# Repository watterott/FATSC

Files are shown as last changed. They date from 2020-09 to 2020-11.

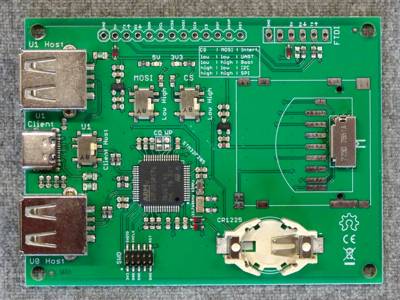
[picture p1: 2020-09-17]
hardware/FATSC-DevKit_v10.jpg

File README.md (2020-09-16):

# FATSC
FATSC (FAT Storage Controller) is a SD/USB coprocessor to connect USB memory sticks or SD cards to a microcontroller.

* USB-Host MSD/MSC port
* SD-Card interface
* Real-Time-Clock (RTC)
* FAT/FAT32 file system
* Based on a ST STM32F205 ARM microcontroller
* ALFAT compatible pinout and commands
* **[Documentation on learn.watterott.com](https://learn.watterott.com)**

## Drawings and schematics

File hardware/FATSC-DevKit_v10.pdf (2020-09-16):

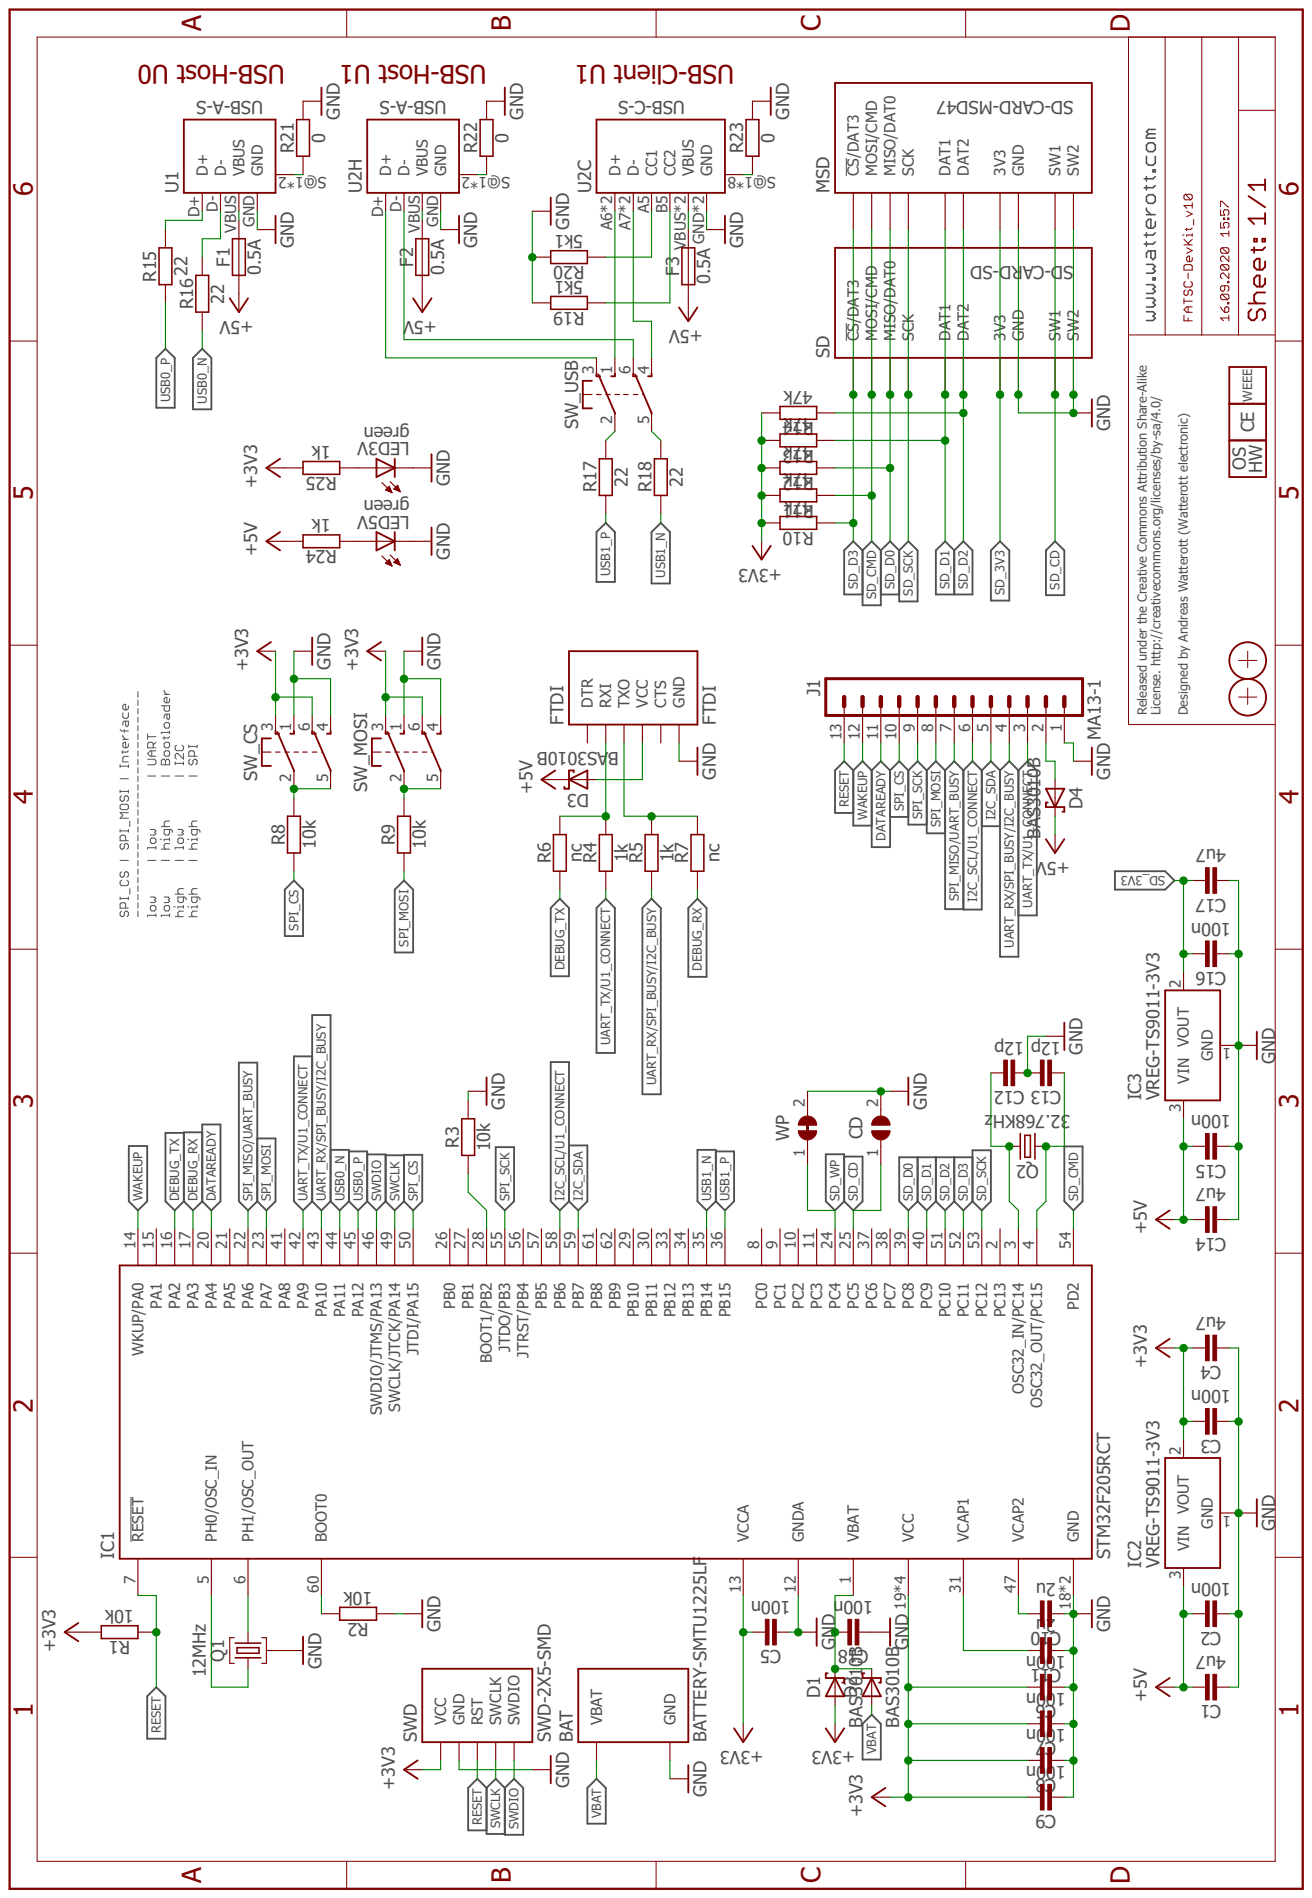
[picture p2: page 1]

Released under the Creative Commons Attribution Share-Alike

2 OS HW CE WEEE

License. http://creativecommons.org/licenses/by-sa/4.0/ Designed by Andreas Watterott (Watterott electronic)

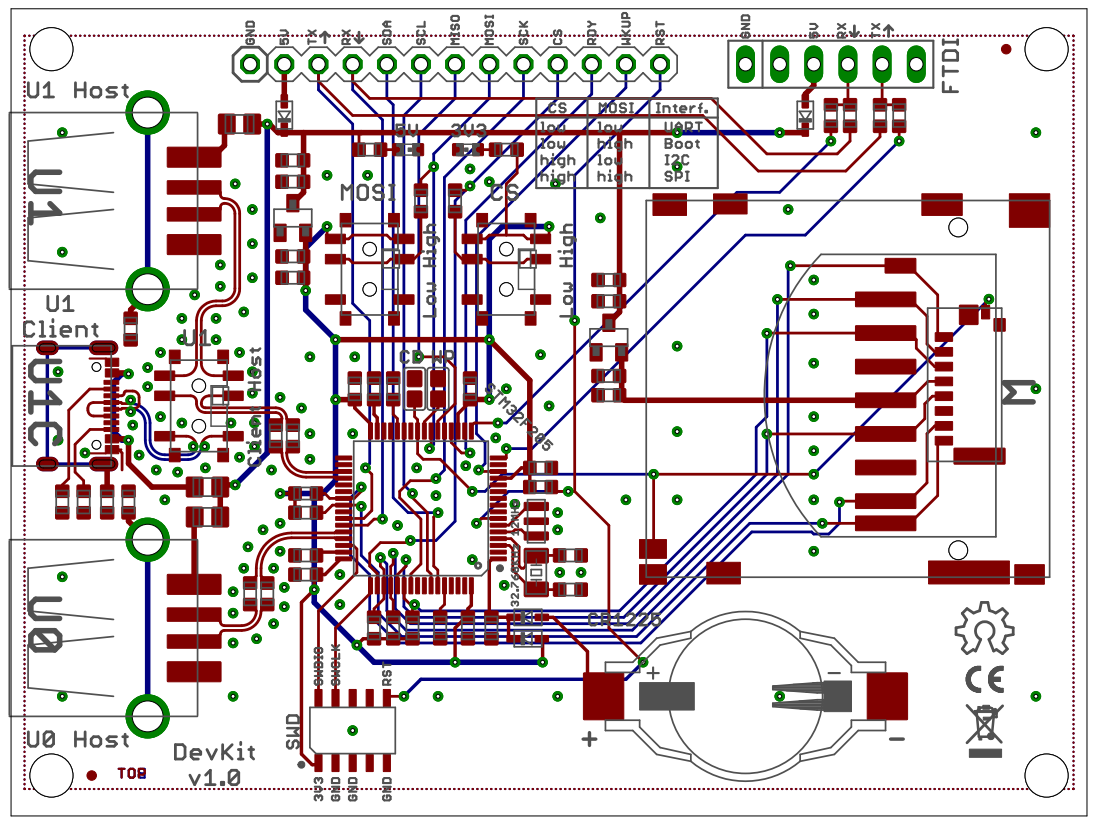
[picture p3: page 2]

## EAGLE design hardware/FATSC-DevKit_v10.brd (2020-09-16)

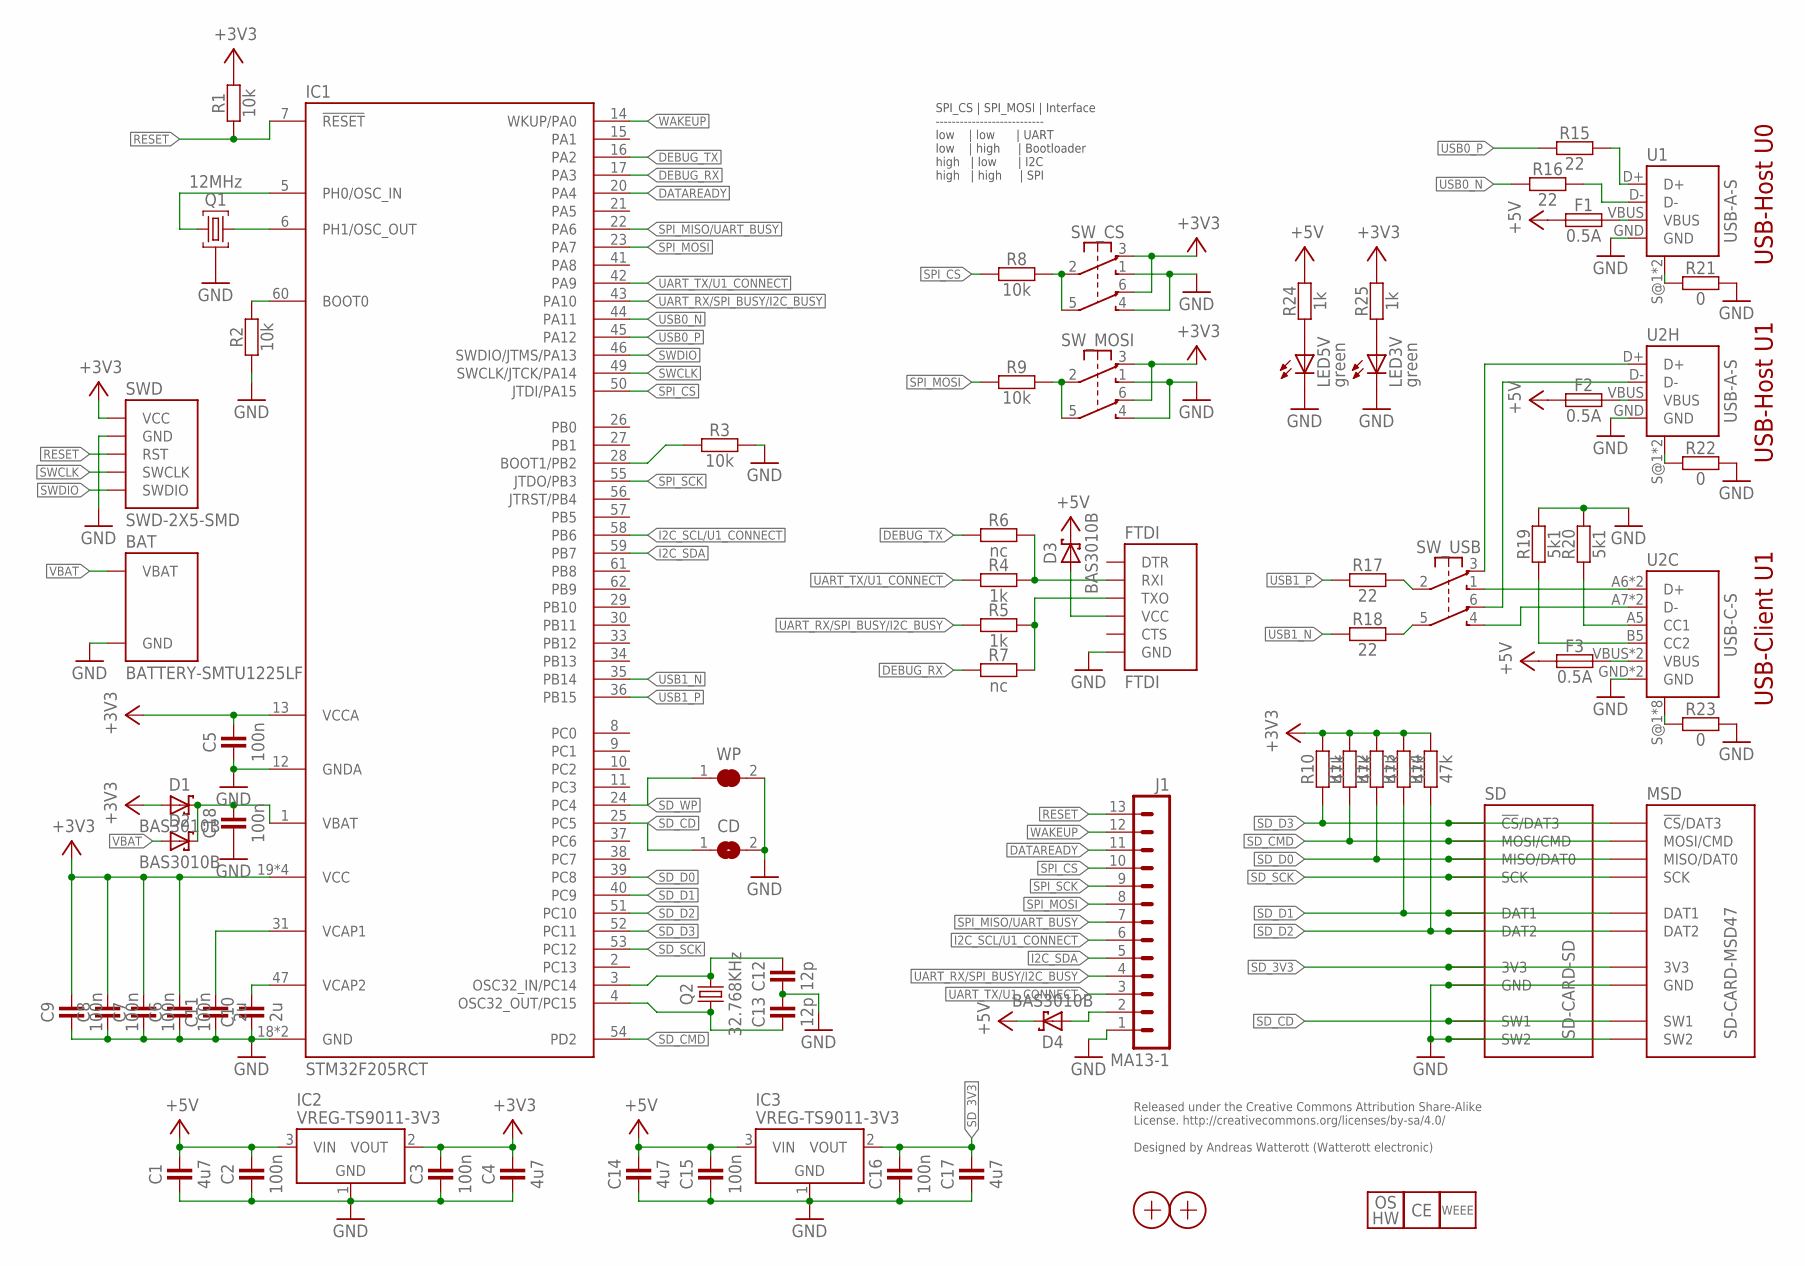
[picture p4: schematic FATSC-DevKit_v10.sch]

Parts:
BAT: BATTERY-SMTU1225LF; BAT-SMTU1225LF
C1, C4, C14, C17: 4u7; C0603
C2, C3, C5, C6, C7, C8, C9, C15, C16, C18: 100n; C0603
C10, C11: 2u; C0603
C12, C13: 12p; C0603
CD: JUMPER2-0603-NC; JUMPER2-0603_NC
D1, D2, D3, D4: BAS3010B; SOD323
F1, F2, F3: 0.5A; C0805
FTDI: FTDI
IC1: STM32F205RCT; LQFP64
IC2, IC3: VREG-TS9011-3V3; SOT23
J1: MA13-1
LED3V, LED5V: green; C0603
LOGO7: LOGO_OSHW-4; OSHW_4MM
LOGO8: LOGO_CE-2; CE_2MM
LOGO9: LOGO_WEEE-4; WEEE_4MM
MSD: SD-CARD-MSD47; SD_47309XXXX
Q1: 12MHz; CRYSTAL_32X13
Q2: 32.768KHz; CRYSTAL_ZM315
R1, R2, R3, R8, R9: 10k; C0603
R4, R5, R24, R25: 1k; C0603
R6, R7: nc; C0603
R10, R11, R12, R13, R14: 47k; C0603
R15, R16, R17, R18: 22; C0603
R19, R20: 5k1; C0603
R21, R22, R23: 0; C0603
SD: SD-CARD-SD; SD_SDBMF00915B0T2
SWD: SWD-2X5-SMD; SWD-2X5_SMD
SW_CS: SW-2UM-CUS22B; CUS22B
SW_MOSI: SW-2UM-CUS22B; CUS22B
SW_USB: SW-2UM-CUS22B; CUS22B
U1, U2H: USB-A-S
U2C: USB-C-S
WP: JUMPER2-0603
X1, X2: PASSER-07; PASSER_07MM

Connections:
5VIN: D4.A, J1.2
+3V3: C3.2, C4.2, C5.2, C6.2, C7.2, C8.2, C9.2, D1.A, IC1.13 (VCCA), IC1.19 (VCC), IC1.32 (VCC), IC1.48 (VCC), IC1.64 (VCC), IC2.2 (VOUT), R1.2, R10.2, R11.2, R12.2, R13.2, R14.2, R25.2, SWD.VCC, SW_CS.3 (NC1), SW_CS.6 (NC2), SW_MOSI.3 (NC1), SW_MOSI.6 (NC2)
+5V: C1.2, C2.2, C14.2, C15.2, D3.C, D4.C, F1.1, F2.1, F3.1, IC2.3 (VIN), IC3.3 (VIN), R24.2
BOOT0: IC1.60 (BOOT0), R2.2
BOOT1: IC1.28 (BOOT1/PB2), R3.1
CC1: R20.1, U2C.A5 (CC1)
CC2: R19.1, U2C.B5 (CC2)
CS: R8.2, SW_CS.2 (C1), SW_CS.5 (C2)
D0_N: R16.2, U1.D-
D0_P: R15.2, U1.D+
D1C_N: SW_USB.4 (NO2), U2C.A7 (D-), U2C.B7 (D-)
D1C_P: SW_USB.1 (NO1), U2C.A6 (D+), U2C.B6 (D+)
D1H_N: SW_USB.6 (NC2), U2H.D-
D1H_P: SW_USB.3 (NC1), U2H.D+
D1_N: R18.2, SW_USB.5 (C2)
D1_P: R17.2, SW_USB.2 (C1)
DATAREADY: IC1.20 (PA4), J1.11
DEBUG_RX: IC1.17 (PA3), R7.1
DEBUG_TX: IC1.16 (PA2), R6.1
FTDI_VCC: D3.A, FTDI.3-VCC (VCC)
GND: BAT.- (GND), C1.1, C2.1, C3.1, C4.1, C5.1, C6.1, C7.1, C8.1, C9.1, C10.1, C11.1, C12.1, C13.2, C14.1, C15.1, C16.1, C17.1, C18.1, CD.2, FTDI.1-GND (GND), IC1.12 (GNDA), IC1.18 (GND), IC1.63 (GND), IC2.1 (GND), IC3.1 (GND), J1.1, LED3V.C, LED5V.C, MSD.GND, MSD.GND@1 (GND), MSD.GND@2 (GND), MSD.SW2, Q1.GND, R2.1, R3.2, R19.2, R20.2, R21.2, R22.2, R23.2, SD.GND@1 (GND), SD.GND@2 (GND), SD.GND@3 (GND), SD.SW2, SWD.GND@1 (GND), SWD.GND@2 (GND), SWD.GND@3 (GND), SW_CS.1 (NO1), SW_CS.4 (NO2), SW_MOSI.1 (NO1), SW_MOSI.4 (NO2), U1.GND, U2C.GND, U2C.GND2 (GND), U2H.GND, WP.2
I2C_SCL/U1_CONNECT: IC1.58 (PB6), J1.6
I2C_SDA: IC1.59 (PB7), J1.5
MOSI: R9.2, SW_MOSI.2 (C1), SW_MOSI.5 (C2)
unnamed: LED5V.A, R24.1
unnamed: LED3V.A, R25.1
OSC32I: C12.2, IC1.3 (OSC32_IN/PC14), Q2.2
OSC32O: C13.1, IC1.4 (OSC32_OUT/PC15), Q2.1
OSCI: IC1.5 (PH0/OSC_IN), Q1.2
OSCO: IC1.6 (PH1/OSC_OUT), Q1.1
RESET: IC1.7 (!RESET), J1.13, R1.1, SWD.RST
RXI: FTDI.5-RXI (RXI), R4.2, R6.2
SD_3V3: C16.2, C17.2, IC3.2 (VOUT), MSD.VCC (3V3), SD.VCC (3V3)
SD_CD: CD.1, IC1.25 (PC5), MSD.SW1, SD.SW1
SD_CMD: IC1.54 (PD2), MSD.MOSI (MOSI/CMD), R11.1, SD.MOSI (MOSI/CMD)
SD_D0: IC1.39 (PC8), MSD.MISO (MISO/DAT0), R12.1, SD.MISO (MISO/DAT0)
SD_D1: IC1.40 (PC9), MSD.DAT1, R13.1, SD.DAT1
SD_D2: IC1.51 (PC10), MSD.DAT2, R14.1, SD.DAT2
SD_D3: IC1.52 (PC11), MSD.CS (!CS!/DAT3), R10.1, SD.CS (!CS!/DAT3)
SD_SCK: IC1.53 (PC12), MSD.SCK, SD.SCK
SD_WP: IC1.24 (PC4), WP.1
SPI_CS: IC1.50 (JTDI/PA15), J1.10, R8.1
SPI_MISO/UART_BUSY: IC1.22 (PA6), J1.7
SPI_MOSI: IC1.23 (PA7), J1.8, R9.1
SPI_SCK: IC1.55 (JTDO/PB3), J1.9
SU0: R21.1, U1.S@1 (SHIELD), U1.S@2 (SHIELD)
SU1C: R23.1, U2C.S@1 (SHIELD), U2C.S@2 (SHIELD), U2C.S@3 (SHIELD), U2C.S@4 (SHIELD), U2C.S@5 (SHIELD), U2C.S@6 (SHIELD), U2C.S@7 (SHIELD), U2C.S@8 (SHIELD)
SU1H: R22.1, U2H.S@1 (SHIELD), U2H.S@2 (SHIELD)
SWCLK: IC1.49 (SWCLK/JTCK/PA14), SWD.SWCLK
SWDIO: IC1.46 (SWDIO/JTMS/PA13), SWD.SWDIO
TXO: FTDI.4-TXO (TXO), R5.2, R7.2
UART_RX/SPI_BUSY/I2C_BUSY: IC1.43 (PA10), J1.4, R5.1
UART_TX/U1_CONNECT: IC1.42 (PA9), J1.3, R4.1
USB0_N: IC1.44 (PA11), R16.1
USB0_P: IC1.45 (PA12), R15.1
USB1_N: IC1.35 (PB14), R18.1
USB1_P: IC1.36 (PB15), R17.1
VB: C18.2, D1.C, D2.C, IC1.1 (VBAT)
VBAT: BAT.+ (VBAT), D2.A
VBUS_U0: F1.2, U1.VBUS
VBUS_U1C: F3.2, U2C.VBUS, U2C.VBUS2 (VBUS)
VBUS_U1H: F2.2, U2H.VBUS
VCAP1: C11.2, IC1.31 (VCAP1)
VCAP2: C10.2, IC1.47 (VCAP2)
WAKEUP: IC1.14 (WKUP/PA0), J1.12

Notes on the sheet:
Released under the Creative Commons Attribution Share-Alike License. http://creativecommons.org/licenses/by-sa/4.0/ Designed by Andreas Watterott (Watterott electronic)
USB-Host U0
USB-Host U1
USB-Client U1
SPI_CS | SPI_MOSI | Interface --------------------------- low | low | UART low | high | Bootloader high | low | I2C high | high | SPI

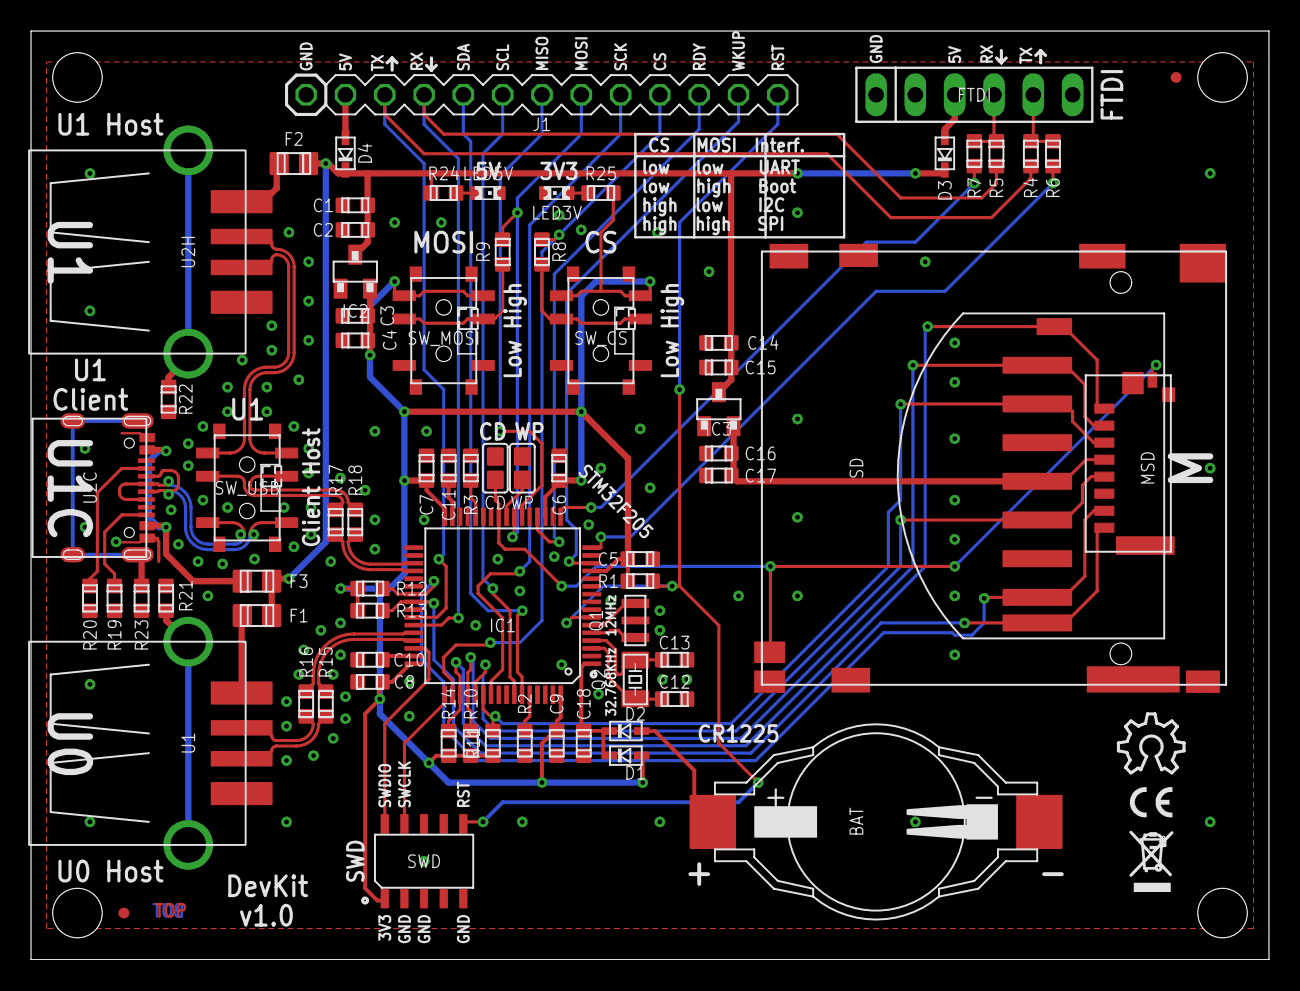
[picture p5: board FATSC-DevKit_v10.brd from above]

Board: 2 copper layers, 80.0 x 60.0 mm, 76 parts (0 on the bottom side), 65 nets.

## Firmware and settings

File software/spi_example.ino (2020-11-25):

/*
  FATSC SPI Demo
 */

#include <SPI.h>


#define RST_PIN    9 //Reset (FATSC reset input pin not 5V tolerant)
#define CS_PIN    10 //CS/SS chip select
#define MOSI_PIN  11 //SDI/MOSI (ICSP: 4, Uno: 11, Mega: 51)
#define MISO_PIN  12 //SDO/MISO (ICSP: 1, Uno: 12, Mega: 50)
#define SCK_PIN   13 //CLK/SCK  (ICSP: 3, Uno: 13, Mega: 52)
#define READY_PIN  8 //Data ready
#define BUSY_PIN   7 //Busy

#define BYTE_PAUSE 5 //us pause between SPI data bytes

#define CR    0x0D
#define LF    0x0A
#define SPACE 0x20

#define HEXTONIBBLE(c) (c >= 'A' ? (c-'A')+10 : (c-'0')) //(*(c) >= 'A' ? (*(c)-'A')+10 : (*(c)-'0'))

#define RX_BUFFER_LEN 64 //32, 64, 128 or 256 bytes

unsigned char rxbuffer[RX_BUFFER_LEN];
volatile unsigned char rx_head=0, rx_tail=0;
volatile unsigned int rx_bytes_available=0;


void setup()
{
  int rc;
  char data[32];
  unsigned int len;

  //init serial port
  Serial.begin(115200);
  //while(!Serial); //wait for serial port to connect
  Serial.println(F("--------------"));
  Serial.println(F("FATSC SPI Demo"));
  Serial.println(F("--------------"));

  //init pins
  digitalWrite(RST_PIN, LOW); //low=reset on
  pinMode(RST_PIN, OUTPUT);
  pinMode(CS_PIN, OUTPUT);
  digitalWrite(CS_PIN, HIGH); //high for SPI
  pinMode(MOSI_PIN, OUTPUT);
  digitalWrite(MOSI_PIN, HIGH); //high for SPI
  pinMode(SCK_PIN, OUTPUT);
  digitalWrite(SCK_PIN, LOW);
  pinMode(READY_PIN, INPUT);
  pinMode(BUSY_PIN, INPUT);
  pinMode(MISO_PIN, INPUT);
  delay(10); //wait 10ms
  pinMode(RST_PIN, INPUT); //high-Z, reset not 5V tolerant
  delay(100); //wait 100ms

  //init SPI library: mode 0, MSB first
  SPI.begin();
  SPI.beginTransaction(SPISettings(4000000, MSBFIRST, SPI_MODE0)); //4 MHz clock

  //wait for startup message, ending with result code 0
  delay(1000); //wait 1000ms
  write_cmd("\n"); //send NOP
  do
  {
    rc = read_rc();
  }while(rc != 0x00);
  flush_data();
  Serial.print(F("RC: "));
  Serial.println(rc, HEX);

  //get version
  if(write_cmd("V\n") == 0)
  {
    len = read_line(data, sizeof(data));
    rc = read_rc();
    if((len > 0) && (rc == 0x00))
    {
      Serial.print(F("Version: "));
      Serial.println(data);
    }
  }

  //get date
  if(write_cmd("G D\n") == 0)
  {
    len = read_line(data, sizeof(data));
    rc = read_rc();
    if((len > 0) && (rc == 0x00))
    {
      Serial.print(F("Time: "));
      Serial.println(data);
    }
  }

  //get free size of M:
  write_cmd("I M:\n");
  rc = read_rc();
  if(rc == 0x00)
  {
    Serial.println(F("M: okay"));
    write_cmd("K M:\n");
    rc = read_rc();
    if(rc == 0x00)
    {
      len = read_line(data, sizeof(data));
      rc = read_rc();
      if(rc == 0x00)
      {
        Serial.print(F("M: free: "));
        Serial.println(data);
      }
    }
  }

  Serial.println(F("...done"));
}


void loop()
{
  //do nothing
}


unsigned char spi_transfer(unsigned char txdata)
{
  unsigned char rxdata;

  delayMicroseconds(BYTE_PAUSE);
  rxdata = SPI.transfer(txdata);

  return rxdata;
}


int write_cmd(const char *data)
{
  int ready;
  unsigned int len, i;

  digitalWrite(CS_PIN, LOW); //CS low

  len = strlen(data); //data length

  do
  {
    spi_transfer(0x01); //0x01=write
    ready = spi_transfer(len); //size lsb
  }while(ready != 0x01); //wait for ready byte

  spi_transfer((len>>8)); //size msb

  //write data
  for(i=0; i<len; i++)
  {
    ready = spi_transfer((unsigned char)*data++);
  }

  digitalWrite(CS_PIN, HIGH); //CS high

  return (ready==0x01) ? 0 : -1;
}


unsigned int read_data(void)
{
  unsigned int len, len_a, i;
  unsigned char c;

  len = RX_BUFFER_LEN-rx_bytes_available; //fifo free size

  //delayMicroseconds(100); //ALFAT needs some time between reads

  digitalWrite(CS_PIN, LOW); //CS low

  spi_transfer(0x02); //0x02=read
  len_a  = spi_transfer((len>>0))<<0; //size lsb
  len_a |= spi_transfer((len>>8))<<8; //size msb

  if(len_a > len)
  {
    len_a = len;
  }

  //read data
  for(i=0; i < len_a; i++)
  {
    c = spi_transfer(0x00);
    fifo_putc(c);
  }

  digitalWrite(CS_PIN, HIGH); //CS high

  return len_a;
}


void flush_data(void)
{
  unsigned char c;

  do
  {
    while(rx_bytes_available)
    {
      c = fifo_getc();
    }
  }while(read_data() != 0);

  return;
}


unsigned char fifo_getc()
{
  unsigned char tail, c;

  if(rx_bytes_available == 0)
  {
    while(read_data() == 0); //wait for data
  }

  tail = rx_tail;
  c = rxbuffer[tail++];
  tail = tail & (RX_BUFFER_LEN-1);
  rx_tail = tail;
  rx_bytes_available--;

  return c;
}


void fifo_putc(unsigned char c)
{
  unsigned char head;

  head = rx_head;
  rxbuffer[head++] = c;
  head = head & (RX_BUFFER_LEN-1);
  rx_head = head;
  rx_bytes_available++;

  return;
}


unsigned int read_line(char *dst, unsigned int len)
{
  unsigned char c;
  unsigned int bytes=0;

  len--; //ends with '\0'

  while(1)
  {
    c = fifo_getc();
    if(c == LF)
    {
      break;
    }
    if(bytes < len)
    {
      *dst++ = (char)c;
      bytes++;
    }
  }
  *dst = 0;

  return bytes;
}


int read_rc(void) //!{RR}<LF>
{
  int rc = -1;
  unsigned char c;

  do{
    c = fifo_getc(); //!
    if(c == '!')
    {
      c = fifo_getc();
      if(isxdigit(c))
      {
        rc = HEXTONIBBLE(toupper(c))*16;
        c = fifo_getc();
        if(isxdigit(c))
        {
          rc += HEXTONIBBLE(toupper(c))*1;
          c = fifo_getc(); //LF
        }
      }
    }
  }while(c != LF);

  return rc;
}

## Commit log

2020-09-16 added layout and schematics
    [FATSC-DevKit_v10.brd, FATSC-DevKit_v10.sch]
2020-10-18 updated SPI example
